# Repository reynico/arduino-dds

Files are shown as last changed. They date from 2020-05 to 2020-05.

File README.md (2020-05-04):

Se muestran una serie de reformas y ajustes necesarios para instalar el DDS en
un equipo tipo Cahuane FR-300. Al final del documento encontrarán la forma de
operar el DDS.

- [Reformas](#reformas)
  - [Diagrama esquemático completo](#diagrama-esquem%c3%a1tico-completo)
  - [Pinout del Arduino Nano](#pinout-del-arduino-nano)
  - [Fuente de alimentación](#fuente-de-alimentaci%c3%b3n)
  - [Selector de canales](#selector-de-canales)
  - [Ajuste de frecuencia por encoder rotativo](#ajuste-de-frecuencia-por-encoder-rotativo)
  - [Pantalla LCD](#pantalla-lcd)
  - [DDS AD9850](#dds-ad9850)
  - [S-Meter](#s-meter)
  - [Radiofrecuencia](#radiofrecuencia)
- [Instalación del código en el Arduino Nano](#instalaci%c3%b3n-del-c%c3%b3digo-en-el-arduino-nano)
  - [Subir el código](#subir-el-c%c3%b3digo)
  - [Configuraciones posibles](#configuraciones-posibles)
- [Operación](#operaci%c3%b3n)
  - [VFO](#vfo)
  - [Saltos de incremento](#saltos-de-incremento)
  - [Bandas](#bandas)
  - [Modo de operación (LSB y USB)](#modo-de-operaci%c3%b3n-lsb-y-usb)
  - [Memoria VFO](#memoria-vfo)

# Reformas

## Diagrama esquemático completo
El diagrama eléctrico completo se muestra a continuación. Mas adelante se
detalla cada sección por separado para mejor interpretación

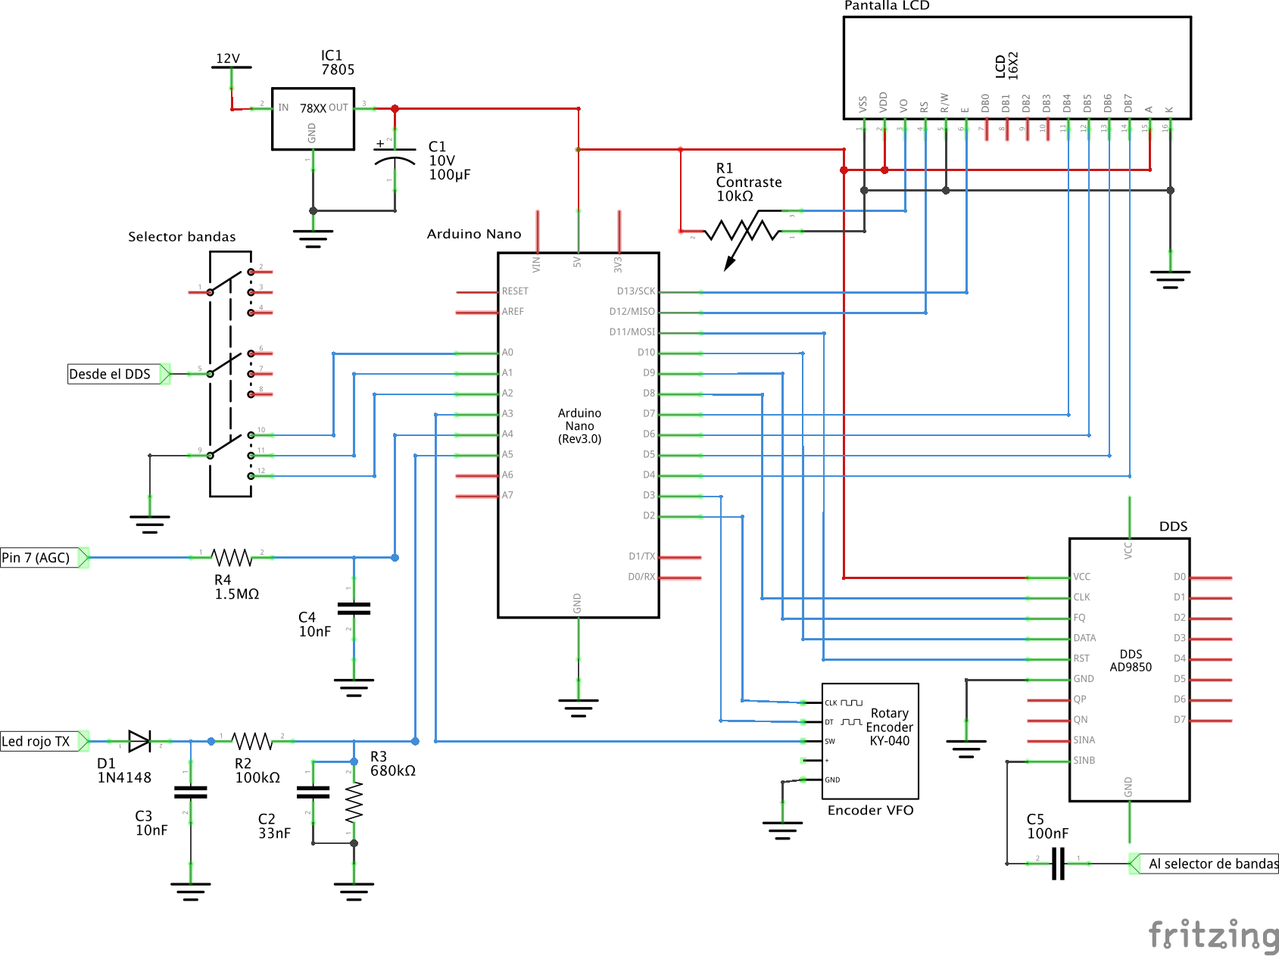
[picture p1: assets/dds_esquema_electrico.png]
Diagrama eléctrico


## Pinout del Arduino Nano
Es importante familiarizarse con la notación de los pines del Arduino Nano. De
esta manera será mas sencillo seguir la guía de ensamble

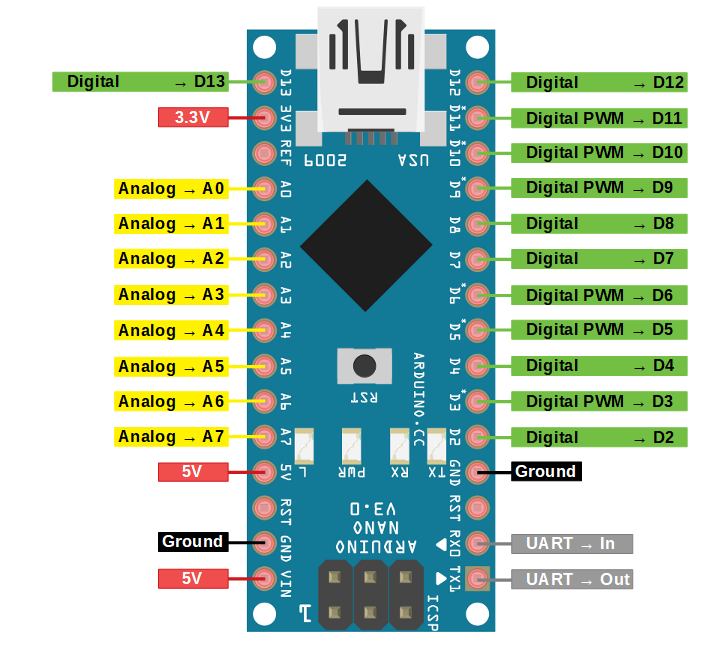
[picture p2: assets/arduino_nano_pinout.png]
Arduino Nano


## Fuente de alimentación
Se utiliza un regulador de tensión de la linea 78xx, en este caso de 5 volts
(7805) con un capacitor electrolítico de 10v y 100uF a la salida para filtrar
cualquier tipo de ruido que pueda traer problemas a la electrónica sensible.

## Selector de canales
El DDS utiliza la llave selectora de canales del equipo para cambiar entre las
diferentes bandas. La llave rotativa tiene una isla completa vacía que puede
utilizarse para este fin

Existe una isla vacía en la llave selectora original, que es la que utilizaremos
para el Arduino de la siguiente manera:

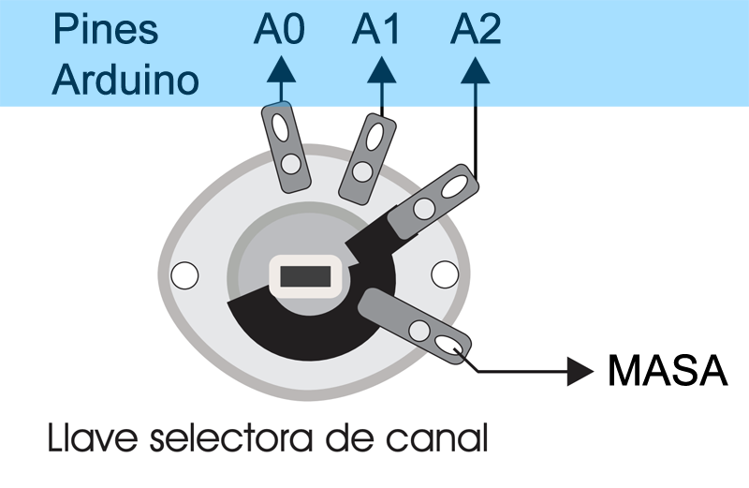
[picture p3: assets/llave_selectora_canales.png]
Llave selectora


Cada pin de la llave selectora es conectada al Arduino Nano. Si no sabe que
pines conectar, por favor refiérase al [pinout del Arduino
Nano](#pinout-del-arduino-nano) descripto anteriormente

## Ajuste de frecuencia por encoder rotativo
El VFO funciona a través de un encoder rotativo. Es un dispositivo que maneja
una señal digital del tipo tren de pulsos. El Arduino interpreta esa información
y el código permite ajustar la frecuencia. También posee un botón que tiene
diferentes usos dependiendo de la forma en que se toque. Para mas información al
respecto, leer la sección [operación](#operaci%c3%b3n).

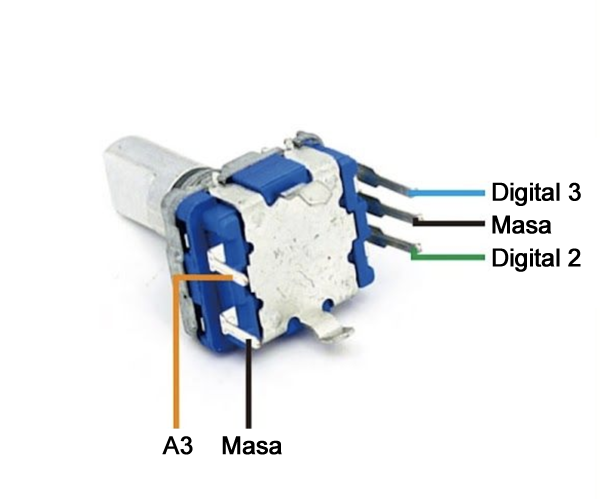
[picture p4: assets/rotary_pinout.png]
Encoder rotativo


## Pantalla LCD
Se utiliza una pantalla LCD de 16x2 caracteres basada en el controlador HD44780.
El contraste se regula a través de un potenciometro que varía la tensión en el
pin `VEE`. Se puede utilizar un potenciometro de 10kohms para ajustar el
contraste hasta el nivel deseado, luego medir la resistencia del potenciometro
en esa posición y colocar una resistencia fija. La iluminación del display se
hace a través de los pines `LED+` y `LED-`. Se puede colocar una resistencia de
pequeño valor si el nivel de luz es demasiado fuerte. Exceptuando la
alimentación por los pines `VSS` y `VCC`, el resto de los pines se conectan
directamente al Arduino.

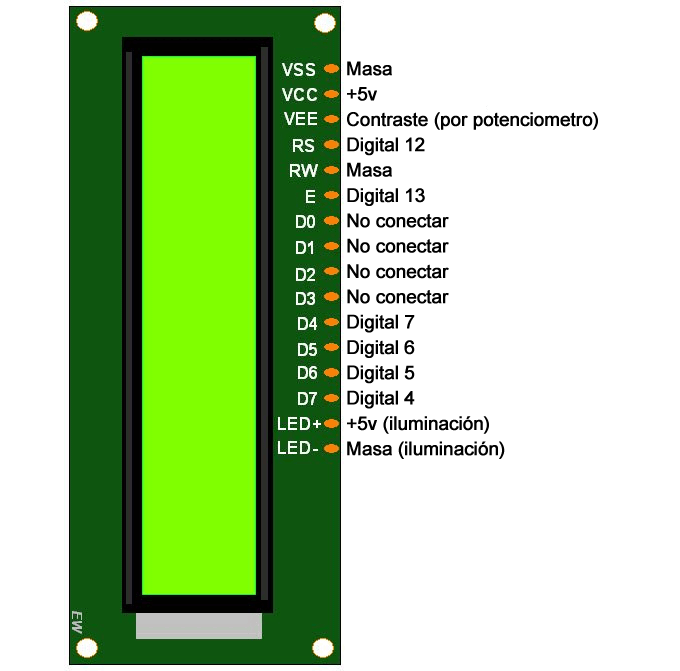
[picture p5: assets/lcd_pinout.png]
Pinout LCD


## DDS AD9850
La conexión al DDS es bastante sencilla. Se necesita alimentación de +5v y masa,
y cuatro pines de control, `W_CLK`, `FQ_UD`, `DATA` y `RESET`. La salida de
antena debe ir conectada conforme se indica en la sección [Radiofrecuencia](#radiofrecuencia).

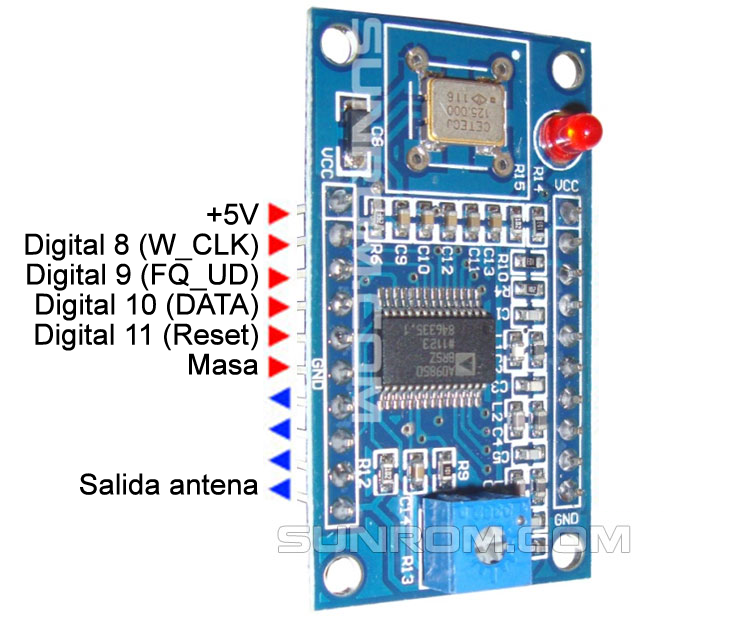
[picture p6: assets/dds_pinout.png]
Pinout DDS


## S-Meter
El S-Meter funciona tanto en transmisión como en recepción. Para el modo de
transmisión se utiliza la tensión existente en el led rojo de TX del equipo

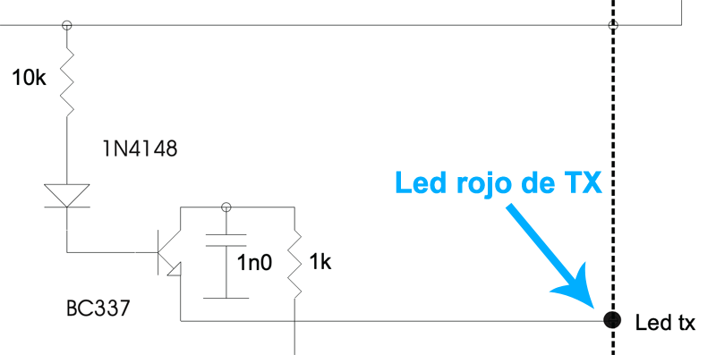
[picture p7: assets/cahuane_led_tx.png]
Cahuane led TX


La señal es acondicionada a través de un diodo `D1` y un divisor resistivo
conformado por `R2` y `R3` y un capacitor a masa. La tensión resultante es
ingresada a través del pin `Analog 5` (A5) del Arduino Nano.

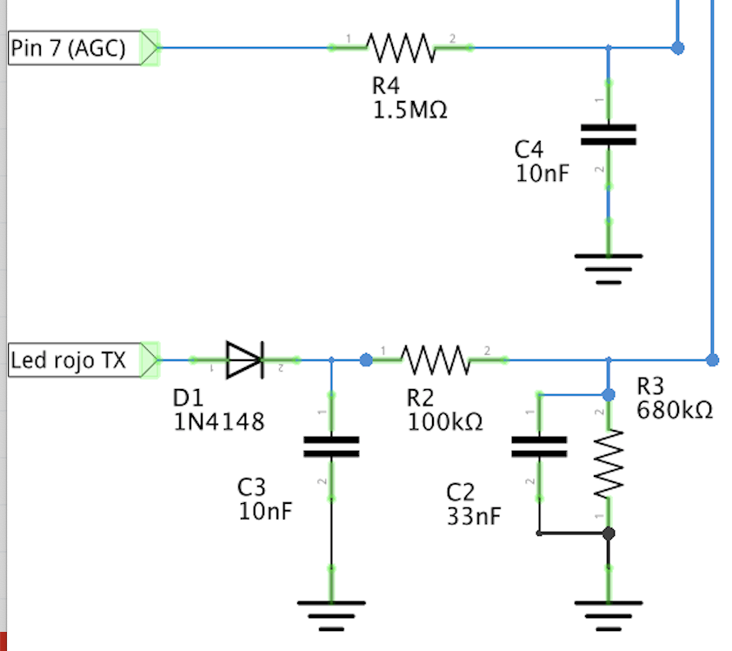
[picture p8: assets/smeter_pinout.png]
S-Meter TX


Para la recepción se utiliza la señal del AGC del equipo que es posteriormente
filtrada con una resistencia `R4` y un capacitor a masa `C4`.

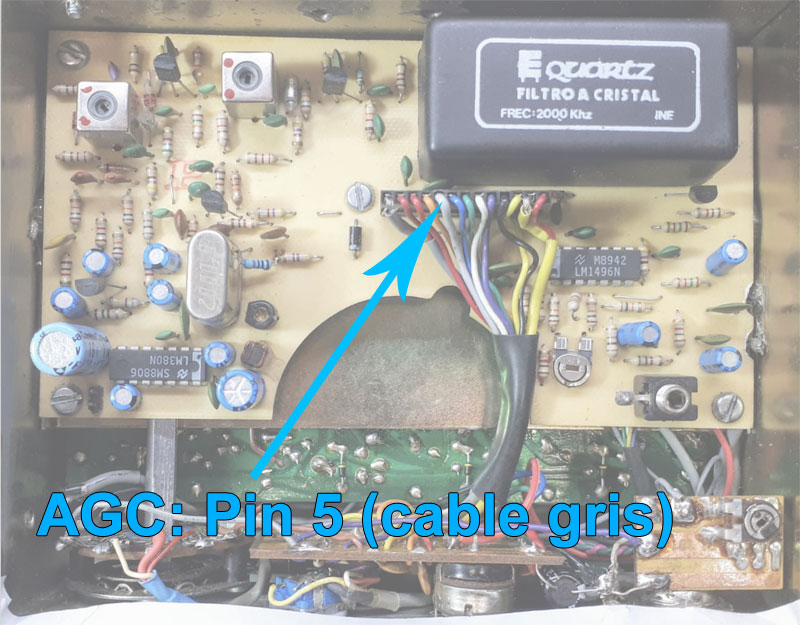
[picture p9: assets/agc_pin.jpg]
Cahuane AGC


## Radiofrecuencia
Se utiliza la salida `SINB` del DDS a través de un capacitor de 100nF para
alimentar la placa PL154 mediante la llave selectora de bandas original.

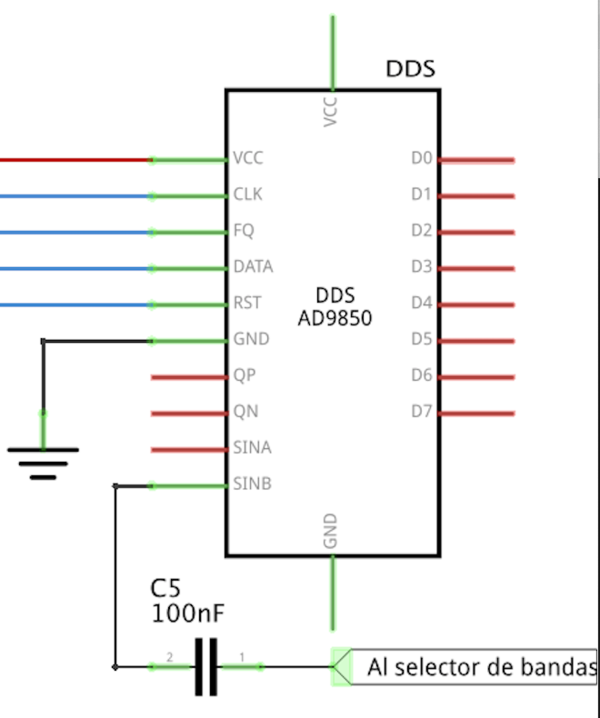
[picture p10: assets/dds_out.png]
Salida DDS


# Instalación del código en el Arduino Nano
Una vez clonado este repositorio, abrir el archivo `dds.ino` en Arduino. Todas
las librerías necesarias están incluidas en el repositorio, de esta manera no
hay que tomarse el trabajo extra de instalar versiones especificas de cada
librería. El código se encuentra comentado para que sea mas sencilla su revisión
y modificación

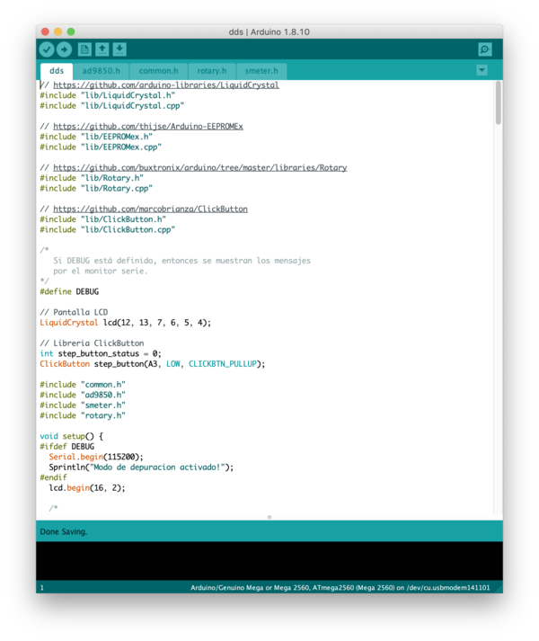
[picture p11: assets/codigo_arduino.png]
Código Arduino


## Subir el código
Con el Arduino Nano conectado a un puerto USB, presionar el botón `Upload` en el
software Arduino

## Configuraciones posibles
* **Modo debug:** El modo debug se utiliza en caso de que algo del funcionamiento
  del DDS no esté ocurriendo como es deseado. Para poder encontrar el problema
  es de utilidad activar los mensajes de depuración. Para esto, descomentar la
  [línea 21](https://github.com/reynico/arduino-dds/blob/master/dds.ino#L21)
* **Pinout:** Se puede variar el pinout de cada parte. Para ello es necesario
  modificar la configuración de los pines en el archivo correspondiente al
  módulo que se desea modificar. En caso de querer cambiar los pines del DDS,
  entonces se debe editar en el archivo [ad9850.h](https://github.com/reynico/arduino-dds/blob/master/ad9850.h)

# Operación

La operación se realiza con dos controles: el selector de banda original (se
utiliza una isla vacía) y un encoder rotativo con botón. El encoder cumple la
función de VFO, sintonizando la frecuencia, y el botón incluído en él tiene
diferentes funciones dependiendo de los toques. Un toque corto cambia el step o
incremento entre 10 Hz, 100 Hz, 1 KHz, 10 KHz, 100 KHz y 1 MHz de manera
ascendente. Dos toques cortos hacen lo mismo de manera descendente. Un toque
largo (+2 segundos) intercambia entre los modos LSB y USB.

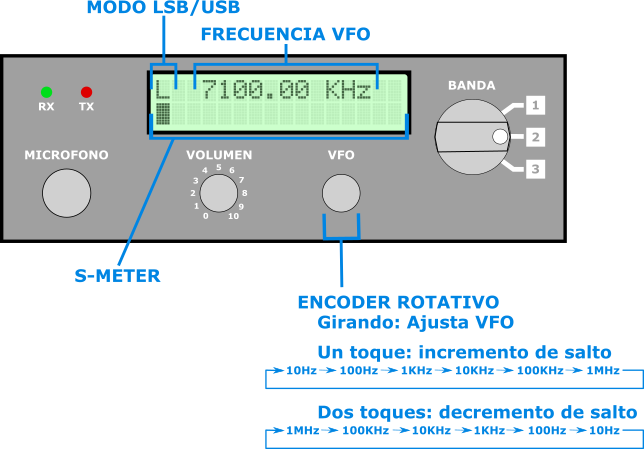
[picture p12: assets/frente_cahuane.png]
Operacion


## VFO
El VFO está programado para funcionar entre 1 a 30 MHz. Girando el encoder
rotativo se ajusta la frecuencia deseada y es mostrada en tiempo real en la
primer línea de la pantalla.

## Saltos de incremento
El botón del encoder cumple la función de posicionar diferentes niveles de
incremento. Con un toque corto el salto aumenta, con dos toques cortos disminuye
como en la siguiente figura:

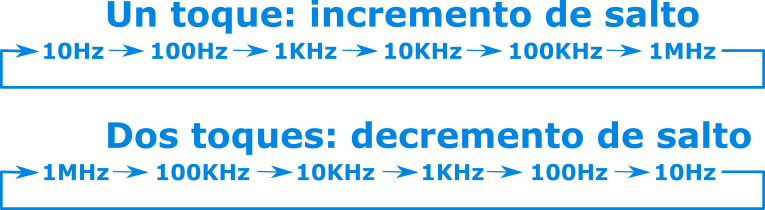
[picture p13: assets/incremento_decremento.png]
Saltos de incremento


El salto de frecuencia es indicado por un segundo en la pantalla, reemplazando
a la frecuencia del VFO por ese período.

## Bandas
Las bandas se activan con la perilla selectora de bandas original. El código
está programado para tener tres bandas: 20, 40 y 60 metros. Esto es modificable

## Modo de operación (LSB y USB)
Si bien cada banda tiene preconfigurado su modo de operación, el modo se puede
invalidar con un pulso largo en el botón de [VFO](#vfo). Ésto cicla los modos
entre USB y LSB y es indicado en la esquina superior izquierda de la pantalla.

## Memoria VFO
El código contempla el uso de la memoria EEPROM del Arduino Nano para guardar la
última frecuencia elegida en el VFO. El guardado en memoria se realiza luego de
dos segundos de inactividad en el encoder rotativo.

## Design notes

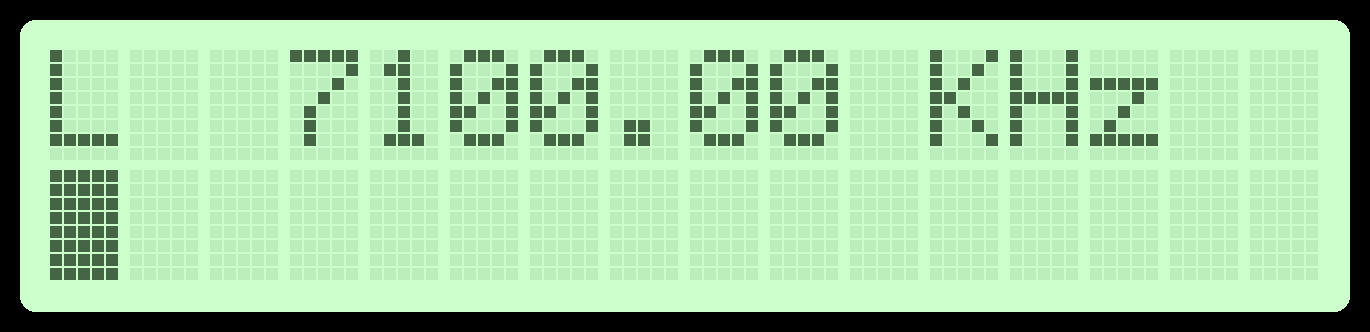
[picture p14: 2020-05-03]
assets/ejemplo_lcd.png

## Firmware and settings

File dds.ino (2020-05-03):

// https://github.com/arduino-libraries/LiquidCrystal
#include "lib/LiquidCrystal.h"
#include "lib/LiquidCrystal.cpp"

// https://github.com/thijse/Arduino-EEPROMEx
#include "lib/EEPROMex.h"
#include "lib/EEPROMex.cpp"

// https://github.com/buxtronix/arduino/tree/master/libraries/Rotary
#include "lib/Rotary.h"
#include "lib/Rotary.cpp"

// https://github.com/marcobrianza/ClickButton
#include "lib/ClickButton.h"
#include "lib/ClickButton.cpp"

/*
   Si DEBUG está definido, entonces se muestran los mensajes
   por el monitor serie.
*/
//#define DEBUG

// Pantalla LCD
LiquidCrystal lcd(12, 13, 7, 6, 5, 4);

// Libreria ClickButton
int step_button_status = 0;
ClickButton step_button(A3, LOW, CLICKBTN_PULLUP);

#include "common.h"
#include "ad9850.h"
#include "smeter.h"
#include "rotary.h"

void setup() {
#ifdef DEBUG
  Serial.begin(115200);
  Sprintln("Modo de depuracion activado!");
#endif
  lcd.begin(16, 2);

  /*
     Creamos los caracteres especiales
     para mostrar en el S-meter.
  */
  byte fillbar[8] = {
    B00000,
    B01000,
    B01100,
    B01010,
    B01001,
    B01010,
    B01100,
    B01000
  };
  byte mark[8] = {
    B00000,
    B01010,
    B10001,
    B10101,
    B10001,
    B01010,
    B00000,
    B00000
  };
  lcd.createChar(0, fillbar);
  lcd.createChar(1, mark);

  /*
     Inicializamos un timer para el encoder rotativo
     de esta manera el encoder no bloquea el flujo
     normal de loop();
  */
  PCICR |= (1 << PCIE2);
  PCMSK2 |= (1 << PCINT18) | (1 << PCINT19);
  sei();

  /*
     Configuramos 4 salidas para controlar el AD9850.
  */
  pinMode(FQ_UD, OUTPUT);
  pinMode(W_CLK, OUTPUT);
  pinMode(DATA, OUTPUT);
  pinMode(RESET, OUTPUT);
  pulse_high(RESET);
  pulse_high(W_CLK);
  pulse_high(FQ_UD);

  /*
     Configuramos tres entradas con pull-up para
     el cambio de banda. Como estamos utilizando
     una única llave para las 3 bandas, utilizamos
     3 pines diferentes de manera digital.
  */
  pinMode(A0, INPUT_PULLUP); // banda 20m
  pinMode(A2, INPUT_PULLUP); // banda 40m
  pinMode(A1, INPUT_PULLUP); // banda 60m

  /*
     El código contempla el uso de la memoria EEPROM del
     Arduino. De esta manera podemos almacenar la última
     frecuencia utilizada y recuperarla al encender el
     equipo.
  */
  if (EEPROM.read(0) == true) {
    Sprintln("Leyendo memoria EEPROM...");
    initial_band = EEPROM.read(1);
    initial_rx = EEPROM.readLong(2);
  } else {
    Sprintln("La memoria EEPROM está vacía. Inicializando con valores por defecto...");
  }
  for (int j = 0; j < 8; j++)
    lcd.createChar(j, block[j]);
  lcd.setCursor(1, 0);
  lcd.print("LU3DJ DDS VFO");
  delay (2000);
  mode = vfo_mode(initial_band);
  lcd.setCursor(0, 0);
  lcd.print(mode);
}

void loop() {
  /* El cambio de banda se realiza con una llave
      giratoria que pone a masa una de las tres
      entradas por vez.
  */
  if (digitalRead(A0) == LOW && band != 20) {
    band = 20;
    mode = vfo_mode(band);
    if (band == initial_band) {
      rx = initial_rx;
    } else {
      rx = 14150000;
    }
  }
  if (digitalRead(A2) == LOW && band != 40) {
    band = 40;
    mode = vfo_mode(band);
    if (band == initial_band) {
      rx = initial_rx;
    } else {
      rx = 7100000;
    }
  }
  if (digitalRead(A1) == LOW && band != 60) {
    band = 60;
    mode = vfo_mode(band);
    if (band == initial_band) {
      rx = initial_rx;
    } else {
      rx = 5360000;
    }
  }

  /*
     Si la frecuencia mostrada es diferente a la frecuencia que
     obtengo al tocar el encoder, la actualizo tanto en la
     pantalla como en el DDS AD9850.
  */
  if (rx != rx2) {
    show_freq();
    send_frequency(rx);
    rx2 = rx;
  }

  /*
     step_button es el botón del encoder rotativo. Con un click
     corto cicla entre los diferentes saltos de incremento. Con
     dis clicks cortos cicla entre los diferentes saltos de
     decremento. Con un click largo cicla los modos USB, LSB y 
     generador*. Generador es un modo en el que la IF no se suma 
     ni se resta y la frecuencia de salida es la mostrada en el display.
  */
  step_button.Update();
  if (step_button.clicks != 0) step_button_status = step_button.clicks;
  if (step_button.clicks == 1) {
    set_increment();
  }
  if (step_button.clicks == 2) {
    set_decrement();
  }
  if (step_button.clicks == -1) {
    if (mode == "U") { 
      /*
       * El modo generador está comentado para que no esté disponible
       * al usar el equipo. Pueden descomentar el bloque inferior
       * si lo desean
       */
      //      mode = "G";
      //      Sprintln("Modo configurado: Generador");
      //      if_freq = 0;
      //      add_if = false;
      //    }
      //    else if (mode == "G") {

      mode = "L";
      Sprintln("Modo configurado: LSB");
      if_freq = 2000000;
      add_if = false;
    }
    else if (mode == "L") {
      mode = "U";
      Sprintln("Modo configurado: USB");
      if_freq = 2000000;
      add_if = true;
    }
    lcd.setCursor(0, 0);
    lcd.print(mode);
  }

  /*
     Luego de sintonizar una frecuencia, si pasaron mas de dos
     segundos la misma se almacena en la memoria EEPROM.
  */
  if (!mem_saved) {
    if (time_passed + 2000 < millis()) {
      store_memory();
    }
  }

  /*
     send_Frequency envía la señal al AD9850.
  */
  send_frequency(rx);

  /*
     El S-meter funciona tanto para transmisión (modulación)
     como para recepción (RF). La forma de cambio es sensando
     el nivel de señal en A4, que es la entrada de señal de RF.
     Si la señal de RF es menor a 90 entonces estamos en
     transmisión y esa es la señal mostrada por el S-meter.
     Caso contrario se mostrará la señal de recepción.
  */
  if (millis() < lastT)
    return;
  lastT += T_REFRESH;
  if (analogRead(A4) < 90) {
    smeter_signal = map(sqrt(analogRead(A5) * 16), 0, 128, 0, 80);
    smeter(1, smeter_signal);
  } else {
    smeter_signal = map(sqrt(analogRead(A4) * 16), 40, 128, 0, 100);
    smeter(1, smeter_signal);
  }

}

/*
   El incremento de frecuencia se hace de manera
   cíclica por los valores definidos abajo. Cada
   vez que se llama a la función set_increment()
   ésta prepara automáticamente el próximo valor.
*/
void set_increment() {
  switch (increment) {
    case 10:
      increment = 100;
      hertz = "100 Hz";
      hertz_position = 10;
      break;
    case 100:
      increment = 1000;
      hertz = "1 Khz";
      hertz_position = 11;
      break;
    case 1000:
      increment = 10000;
      hertz = "10 Khz";
      hertz_position = 10;
      break;
    case 10000:
      increment = 100000;
      hertz = "100 Khz";
      hertz_position = 9;
      break;
    case 100000:
      increment = 1000000;
      hertz = "1 Mhz";
      hertz_position = 11;
      break;
    default:
      increment = 10;
      hertz = "10 Hz";
      hertz_position = 11;
      break;
  }
  Sprint("Salto: ");
  Sprintln(hertz);
  lcd.setCursor(1, 0);
  lcd.print("              ");
  lcd.setCursor(6, 0);
  lcd.print(hertz);
  delay(1000);
  show_freq();
}

void set_decrement() {
  switch (increment) {
    case 1000000:
      increment = 100000;
      hertz = "100 Khz";
      hertz_position = 10;
      break;
    case 100000:
      increment = 10000;
      hertz = "10 Khz";
      hertz_position = 11;
      break;
    case 10000:
      increment = 1000;
      hertz = "1 Khz";
      hertz_position = 10;
      break;
    case 1000:
      increment = 100;
      hertz = "100 Hz";
      hertz_position = 9;
      break;
    case 100:
      increment = 10;
      hertz = "10 Hz";
      hertz_position = 11;
      break;
    case 10:
      increment = 1000000;
      hertz = "1 Mhz";
      hertz_position = 11;
      break;
  }
  Sprint("Salto: ");
  Sprintln(hertz);
  lcd.setCursor(1, 0);
  lcd.print("              ");
  lcd.setCursor(6, 0);
  lcd.print(hertz);
  delay(1000);
  show_freq();
}

/*
   Ésta función se encarga de mostrar la frecuencia
   en pantalla.
*/
void show_freq() {
  lcd.setCursor(1, 0);
  lcd.print("              ");
  if (rx < 10000000) {
    lcd.setCursor(3, 0);
  } else {
    lcd.setCursor(2, 0);
  }
  lcd.print(rx / 1000);
  lcd.print(".");
  lcd.print((rx / 100) % 10);
  lcd.print((rx / 10) % 10);
  lcd.print(" KHz ");
  Sprint("Frecuencia: ");
  Sprintln(rx);
  time_passed = millis();
  mem_saved = false; // Triggerea el guardado en memoria
}

/*
   store_memory() guarda la frecuencia elegida en la memoria
   EEPROM cada vez que se llama.
*/
void store_memory() {
  EEPROM.write(0, true);
  EEPROM.write(1, band);
  EEPROM.writeLong(2, rx);
  mem_saved = true;
  Sprintln("Frecuencia almacenada en memoria EEPROM.");
}

/*
   vfo_mode devuelve el modo en el que se configuró
   el DDS, dependiendo de la banda elegida.
*/
String vfo_mode (int initial_band) {
  if_freq = 2000000;
  lcd.setCursor(0, 0);
  switch (initial_band) {
    case 20:
      add_if = true;
      lcd.print("U");
      return "U";
      break;
    case 40:
      add_if = false;
      lcd.print("L");
      return "L";
      break;
    case 60:
      add_if = true;
      lcd.print("U");
      return "U";
      break;
    case 80:
      add_if = false;
      lcd.print("L");
      return "L";
      break;
  }
}

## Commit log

2020-05-04 S-Meter, step inc/dec
    [dds_schematic.fzz]
2020-05-04 AGC wrong pin
2020-05-04 DDS output
    [dds_schematic.fzz]
